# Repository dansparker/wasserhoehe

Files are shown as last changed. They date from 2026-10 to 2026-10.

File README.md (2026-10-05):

# wasserhoehe

Misst die Wasserhöhe in einem ca. 3 m tiefen Brunnenschacht per Ultraschall und schickt den Wert über Zigbee an Home Assistant (Zigbee2MQTT).

```
JSN-SR04T ──► STM32F103 (Bluepill) ──UART──► CC2530 (PTVO-Firmware) ──Zigbee──► Zigbee2MQTT ──► Home Assistant
```

## Hardware

| Teil | Aufgabe |
|---|---|
| JSN-SR04T (wasserdicht) | Abstand Sensor → Wasseroberfläche, 25–450 cm |
| STM32F103C8T6 Bluepill | Messung, Filterung, Sendelogik |
| TENSTAR CC2530 | Zigbee-Router mit [PTVO-Firmware](https://ptvo.info/zigbee-configurable-firmware-features/) (UART → Zigbee) |
| DS18B20 wasserdicht (optional) | Lufttemperatur im Schacht für die Schallgeschwindigkeit |
| 5-V-Netzteil (≥ 1 A) | Versorgung |

### Verdrahtung

| Von | Nach | Hinweis |
|---|---|---|
| Netzteil +5 V | JSN-SR04T **5V**, Bluepill **5V** | |
| Netzteil GND | JSN-SR04T **GND**, Bluepill **GND**, CC2530 **GND** | gemeinsame Masse! |
| Bluepill **3.3** | CC2530 **VCC** | bei CC2530 mit Verstärker (CC2591) besser eigener AMS1117-3.3 |
| Bluepill **PB7** | JSN-SR04T **Trig** | 3,3 V reichen |
| JSN-SR04T **Echo** | Bluepill **PB6** | 5-V-Pegel, PB6 ist 5-V-tolerant |
| Bluepill **PA9** (TX) | CC2530 **P0.2** (RX) | 9600 Baud, 8N1, beide 3,3 V |
| DS18B20 **DQ** (gelb) | Bluepill **PB8** | optional; **4,7 kΩ** von DQ nach 3,3 V |
| DS18B20 **VDD** (rot) / **GND** (schwarz) | Bluepill **3.3** / **GND** | nicht parasitär betreiben |

PC13 (Onboard-LED) leuchtet während einer Messung.

### Montage

- Elektronik in einer Box **oben** am Schachtdeckel, nur der wasserdichte Schallkopf hängt im Schacht (Kabel 2,5 m).
- Schallkopf **senkrecht und mittig** ausrichten, Abstand zu Wänden, Leitern und Rohren: Der Schallkegel ist breit (≈ 45–75°), Wandechos sind der häufigste Messfehler.
- Den DS18B20 neben dem Schallkopf **in der Schachtluft** aufhängen, nicht in der Box und nicht im Wasser.
- `MOUNT_MM` in [main.c](firmware/src/main.c) = Abstand von der Schallkopf-Fläche zum Schachtboden.
- Die Antenne bzw. den CC2530 nicht unter einem Metall- oder Betondeckel einbauen, sonst kommt kaum Funk durch.

## Gehäuse (3D-Druck)

Im Ordner [gehaeuse/](gehaeuse/) liegen die fertigen STL-Dateien und das parametrische Skript [gehaeuse.py](gehaeuse/gehaeuse.py). Neu erzeugen mit `pip install manifold3d numpy`, dann `python gehaeuse.py`.

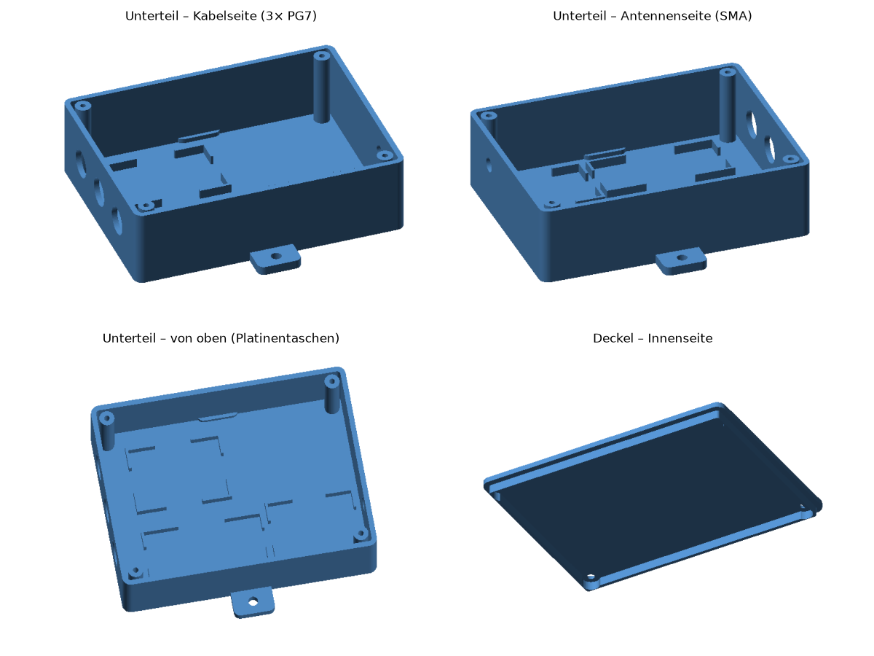
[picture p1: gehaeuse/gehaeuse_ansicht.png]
Gehäuse


| | |
|---|---|
| Außenmaß | 120 × 91 × 34 mm (Unterteil) + 2,4 mm Deckel, Laschen für 4-mm-Schrauben |
| Innen | Taschen für Bluepill, CC2530 und die JSN-Platine (Rippen mit Kabeldurchlässen; Platinen mit Heißkleber oder doppelseitigem Klebeband fixieren) |
| Kabelseite | 3 × Ø 12,5 mm für **PG7-Kabelverschraubungen**: Ultraschallsensor, DS18B20, Netzteil |
| Gegenseite | Ø 6,5 mm für eine **SMA-Antennenbuchse** (`ANT_D = 0` → kein Loch, falls der CC2530 eine PCB-Antenne hat) |
| Deckel | Innenliegender Rand, 4 × M3-Senkkopf, in Dome mit 2,5-mm-Loch (selbstschneidend) |

**Druck:** PETG oder ASA (PLA wird im feuchten Schacht weich und spröde), 0,2-mm-Schichten, 3 Wände, ohne Stützen. Das Unterteil steht aufrecht, der Deckel liegt mit der Außenseite nach unten.

**Einbau:** Die Kabelverschraubungen sollen **nach unten** zeigen, dann läuft Tropfwasser ab. Für Dichtheit eine Silikonraupe oder ein Moosgummiband unter den Deckelrand legen und einen **Silica-Gel-Beutel** ins Gehäuse geben. Wichtig: Die Maße der TENSTAR-Platine vor dem Druck nachmessen und in `BOARDS` eintragen.

## Messverfahren

Messprinzip

Jede Messung besteht aus 9 Pings. Ungültige Werte und Wandechos werden verworfen, der Rest gemittelt:

Filterung

Gesendet wird nur, wenn sich etwas ändert oder das Heartbeat-Intervall abgelaufen ist:

Sendelogik

## Übertragung / Intervall

| Parameter | Wert | Begründung |
|---|---|---|
| Messung | alle **10 s**, je 9 Pings (70 ms Abstand) | Der Pegel ändert sich langsam; mehrere Pings filtern Ausreißer |
| Senden bei Änderung | **≥ 1 cm** | Pumpen oder Nachfüllen sind sofort sichtbar |
| Heartbeat | spätestens alle **5 min** | Home Assistant erkennt, ob das Gerät noch lebt; ein verlorenes Paket wird so wieder ausgeglichen |
| Fehlermeldung | erst nach **3 Fehlmessungen** in Folge | kein Flattern bei einzelnen Störungen |

Das ergibt im Ruhezustand ca. 12 Nachrichten pro Stunde. Weil das Gerät am Netzteil hängt, läuft der CC2530 als **Router** und verstärkt damit auch das Zigbee-Netz.

Telegramm (ASCII): `L=1800;D=1200;S=0;T=9` – Pegel in mm, Distanz in mm, Status (0 = OK, 1 = kein Echo, 2 = instabil), verwendete Temperatur in °C.

**Temperatur:** Ist ein DS18B20 angeschlossen, startet bei jeder Messung eine Wandlung, die parallel zu den Pings läuft. Fehlt der Sensor, rechnet die Firmware mit `TEMP_DEFAULT_C` = 10 °C. Einzelne Lesefehler überbrückt der letzte gültige Wert (bis 1 min). Fehlerhafte Werte werden verworfen: CRC-Fehler, der 85-°C-Einschaltwert und alles außerhalb von −40…60 °C.

## Firmware STM32

PlatformIO (CMSIS, ohne HAL):

```bash
cd firmware
pio run -t upload
```

Zum Flashen braucht man einen ST-Link (SWDIO, SWCLK, GND, 3.3V). Messintervall, Schwellwerte und Temperatur stehen oben in [main.c](firmware/src/main.c).

## Firmware CC2530 (PTVO)

Für eine eigene Z-Stack-Firmware bräuchte man den kostenpflichtigen IAR-8051-Compiler. Deshalb läuft auf dem CC2530 die kostenlose PTVO-Firmware.

1. Den PTVO-Konfigurator von [ptvo.info](https://ptvo.info) laden.
2. Einstellungen: Board **CC2530**, Device type **Router**, Output **UART** mit 9600 Baud. Die Pins (Standard RX = P0.2, TX = P0.3) im Konfigurator kontrollieren.
3. Die Firmware mit einem CC-Debugger (oder einem Arduino oder ESP mit CCLib) flashen.
4. In Zigbee2MQTT „Permit join“ aktivieren und das Gerät in **brunnen** umbenennen. Die per UART empfangenen Zeilen kommen als `action` an.
5. Den Inhalt von [homeassistant/brunnen.yaml](homeassistant/brunnen.yaml) in die Home-Assistant-Konfiguration übernehmen.

## Tests

Die Messlogik ([level.c](firmware/src/level.c)) hängt nicht von der Hardware ab und wird am PC getestet:

```bash
cd test
python -m ziglang cc -I../firmware/src test_level.c ../firmware/src/level.c -o t.exe && ./t.exe
```

Getestet werden Umrechnung, DS18B20-Dekodierung (CRC, negative Werte, 85-°C-Einschaltwert, offener oder kurzgeschlossener Bus), Temperatureinfluss, Ausreißer (Wandecho, Timeout, Blindzone), kein Echo, starke Streuung, leerer Schacht, Array-Überlauf, Sendelogik (Delta, Heartbeat, Fehlerentprellung), Zähler-Überlauf nach 49 Tagen und das Telegramm-Format.

## Bekannte Schwachstellen und Gegenmaßnahmen

| Schwachstelle | Gegenmaßnahme |
|---|---|
| Wandechos oder Leiter im Schacht | Median + Mittelung nur im ±3-cm-Fenster, mindestens 5 von 9 Echos nötig, sonst Status „instabil“ |
| Wasser < 25 cm unter Sensor (Blindzone) | wird als Fehler gemeldet; Sensor ≥ 30 cm über max. Wasserstand montieren |
| Schallgeschwindigkeit hängt von der Temperatur ab (≈ 5 mm pro °C bei 3 m) | DS18B20 im Schacht (optional), sonst fest 10 °C. Der interne STM32-Sensor ist ungeeignet (misst den Chip, ab Werk ±20 °C) |
| Kondenswasser am Schallkopf | Schallkopf leicht schräg bzw. mit Abtropfkante montieren; zeigt sich als „kein Echo“ |
| Bluepill-Clone ohne funktionierenden Quarz | Automatischer Rückfall auf den internen 8-MHz-Takt |
| Hänger (EMV, Echo-Leitung klemmt) | Hardware-Watchdog (~26 s), Timeouts bei allen Warteschleifen |
| Kabelbruch Echo-Leitung | Pull-down an PB6 → Status „kein Echo“ |
| Funkverlust | Heartbeat alle 5 min; CC2530 als Router meldet sich automatisch wieder an |
| CC2530 noch nicht im Netz beim Start | 3 s Startverzögerung, erste verlorene Meldung wird durch Heartbeat ersetzt |

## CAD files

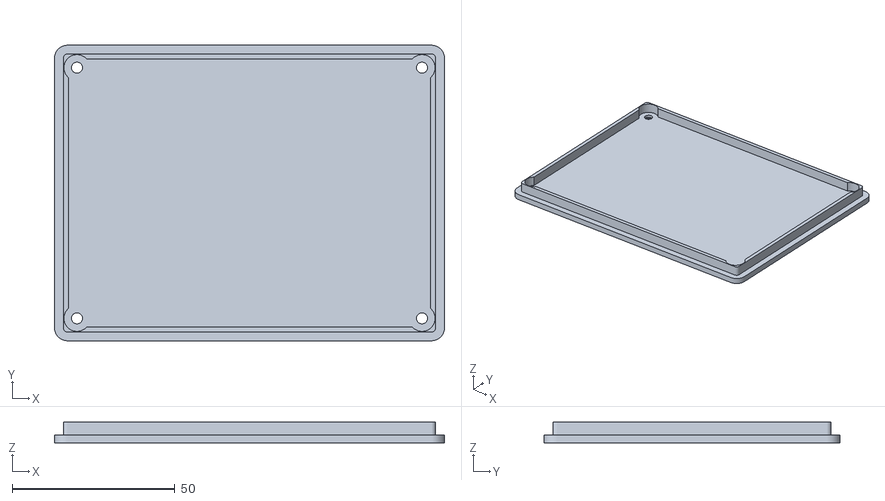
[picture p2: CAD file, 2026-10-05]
gehaeuse/gehaeuse_deckel.stl
119.8 x 90.8 x 6.40

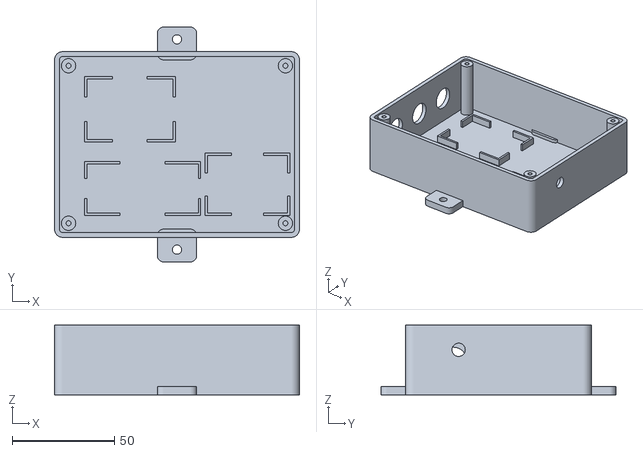
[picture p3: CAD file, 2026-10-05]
gehaeuse/gehaeuse_unterteil.stl
119.8 x 114.8 x 34.0

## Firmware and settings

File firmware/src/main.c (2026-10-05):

/*
 * Wasserhoehe im Brunnenschacht - STM32F103C8T6 (Bluepill)
 *
 *  JSN-SR04T  TRIG -> PB7        ECHO (5 V) -> PB6 (5V-tolerant)
 *  CC2530     RX (P0.2) <- PA9 (USART1 TX, 9600 8N1)
 *  DS18B20    DQ -> PB8 (optional, 4,7 kOhm Pull-up nach 3,3 V)
 *  LED        PC13 (aktiv low), blinkt bei jeder Messung
 */
#include "stm32f1xx.h"
#include "level.h"

/* ---------- Konfiguration ------------------------------------------ */
#define MOUNT_MM        3000u    /* Sensorflaeche ueber Schachtboden  */
#define TEMP_DEFAULT_C  10       /* ohne DS18B20 / bei Lesefehler     */
#define TEMP_KEEP       6        /* letzten DS18B20-Wert so oft halten */
#define SAMPLES         9        /* Pings pro Messung                 */
#define PING_GAP_MS     70       /* Nachhall abklingen lassen         */
#define MEAS_PERIOD_MS  10000u   /* alle 10 s messen                  */
#define DELTA_MM        10u      /* senden bei >= 1 cm Aenderung      */
#define HEARTBEAT_MS    300000u  /* spaetestens alle 5 min senden     */
#define FAIL_LIMIT      3        /* Fehler erst nach 3 Fehlmessungen  */
#define UART_BAUD       9600u
#define ECHO_TIMEOUT_US 30000u   /* ~5 m                              */

#define TRIG_PIN  (1u << 7)
#define ECHO_PIN  (1u << 6)
#define LED_PIN   (1u << 13)
#define OW_PIN    (1u << 8)
#define ECHO_HIGH (GPIOB->IDR & ECHO_PIN)

static volatile uint32_t ms_ticks;
static uint32_t sysclk_hz, pclk1_tim_hz, pclk2_hz;

void SysTick_Handler(void) { ms_ticks++; }

static void clock_init(void)
{
    /* HSE 8 MHz -> PLL x9 = 72 MHz; Fallback HSI 8 MHz (Clone ohne Quarz) */
    RCC->CR |= RCC_CR_HSEON;
    for (uint32_t t = 0; t < 200000u && !(RCC->CR & RCC_CR_HSERDY); t++) { }

    if (RCC->CR & RCC_CR_HSERDY) {
        FLASH->ACR = FLASH_ACR_PRFTBE | FLASH_ACR_LATENCY_2;
        RCC->CFGR  = RCC_CFGR_PLLSRC | RCC_CFGR_PLLMULL9 | RCC_CFGR_PPRE1_DIV2;
        RCC->CR   |= RCC_CR_PLLON;
        while (!(RCC->CR & RCC_CR_PLLRDY)) { }
        RCC->CFGR |= RCC_CFGR_SW_PLL;
        while ((RCC->CFGR & RCC_CFGR_SWS) != RCC_CFGR_SWS_PLL) { }
        sysclk_hz = 72000000u; pclk1_tim_hz = 72000000u; pclk2_hz = 72000000u;
    } else {
        RCC->CR &= ~RCC_CR_HSEON;
        sysclk_hz = pclk1_tim_hz = pclk2_hz = 8000000u;
    }
}

static void periph_init(void)
{
    RCC->APB2ENR |= RCC_APB2ENR_IOPAEN | RCC_APB2ENR_IOPBEN | RCC_APB2ENR_IOPCEN
                  | RCC_APB2ENR_USART1EN;
    RCC->APB1ENR |= RCC_APB1ENR_TIM2EN;

    /* PB7 Push-Pull 2 MHz, PB6 Eingang mit Pull-down (offenes Kabel = low) */
    GPIOB->CRL = (GPIOB->CRL & ~(0xFFu << 24)) | (0x2u << 28) | (0x8u << 24);
    GPIOB->BRR = TRIG_PIN | ECHO_PIN;
    /* PB8 Open-Drain 2 MHz, losgelassen (1-Wire) */
    GPIOB->CRH = (GPIOB->CRH & ~0xFu) | 0x6u;
    GPIOB->BSRR = OW_PIN;
    /* PA9 AF Push-Pull 2 MHz */
    GPIOA->CRH = (GPIOA->CRH & ~(0xFu << 4)) | (0xAu << 4);
    /* PC13 Push-Pull 2 MHz, LED aus */
    GPIOC->CRH = (GPIOC->CRH & ~(0xFu << 20)) | (0x2u << 20);
    GPIOC->BSRR = LED_PIN;

    /* TIM2: freilaufend, 1 MHz */
    TIM2->PSC = (uint16_t)(pclk1_tim_hz / 1000000u - 1u);
    TIM2->ARR = 0xFFFF;
    TIM2->EGR = TIM_EGR_UG;
    TIM2->CR1 = TIM_CR1_CEN;

    USART1->BRR = (uint16_t)((pclk2_hz + UART_BAUD / 2u) / UART_BAUD);
    USART1->CR1 = USART_CR1_UE | USART_CR1_TE;

    SysTick_Config(sysclk_hz / 1000u);

    /* Watchdog: LSI 40 kHz / 256 * 4095 ~ 26 s */
    IWDG->KR  = 0x5555;
    IWDG->PR  = 6;
    IWDG->RLR = 0xFFF;
    IWDG->KR  = 0xCCCC;
}

static inline void wdg_feed(void) { IWDG->KR = 0xAAAA; }

static void delay_us(uint16_t us)
{
    uint16_t t0 = (uint16_t)TIM2->CNT;
    while ((uint16_t)(TIM2->CNT - t0) < us) { }
}

static void delay_ms(uint32_t ms)
{
    uint32_t t0 = ms_ticks;
    while (ms_ticks - t0 < ms) __WFI();
}

/* Liefert Echo-Laufzeit in us, 0 bei Fehler/Timeout. */
static uint16_t ping_us(void)
{
    uint16_t t0 = (uint16_t)TIM2->CNT;
    while (ECHO_HIGH)                                  /* altes Echo noch aktiv */
        if ((uint16_t)(TIM2->CNT - t0) > ECHO_TIMEOUT_US) return 0;

    GPIOB->BSRR = TRIG_PIN;
    delay_us(20);                                      /* >= 10 us, v3 mag 20 */
    GPIOB->BRR = TRIG_PIN;

    t0 = (uint16_t)TIM2->CNT;
    while (!ECHO_HIGH)
        if ((uint16_t)(TIM2->CNT - t0) > 10000u) return 0;

    __disable_irq();                                   /* SysTick-Jitter vermeiden */
    uint16_t ts = (uint16_t)TIM2->CNT, dt;
    while (ECHO_HIGH) {
        dt = (uint16_t)(TIM2->CNT - ts);
        if (dt > ECHO_TIMEOUT_US) { __enable_irq(); return 0; }
    }
    dt = (uint16_t)(TIM2->CNT - ts);
    __enable_irq();
    return dt;
}

/* ---------- 1-Wire / DS18B20 ------------------------------------------ */
#define OW_LOW()   (GPIOB->BRR  = OW_PIN)
#define OW_REL()   (GPIOB->BSRR = OW_PIN)
#define OW_READ()  ((GPIOB->IDR & OW_PIN) != 0)

static int ow_reset(void)
{
    if (!OW_READ()) return 0;                          /* Bus kurz / kein Pull-up */
    OW_LOW();  delay_us(480);
    __disable_irq();
    OW_REL();  delay_us(70);
    int present = !OW_READ();
    __enable_irq();
    delay_us(410);
    return present;
}

static int ow_bit(int b)
{
    __disable_irq();
    OW_LOW();  delay_us(b ? 3 : 60);
    OW_REL();
    if (b) delay_us(9);
    int r = OW_READ();
    __enable_irq();
    delay_us(b ? 55 : 10);
    return r;
}

static void ow_write(uint8_t v)
{
    for (int i = 0; i < 8; i++, v >>= 1) ow_bit(v & 1u);
}

static uint8_t ow_read(void)
{
    uint8_t v = 0;
    for (int i = 0; i < 8; i++) v |= (uint8_t)(ow_bit(1) << i);
    return v;
}

/* Startet Wandlung (750 ms, laeuft parallel zu den Pings). */
static int ds_start(void)
{
    if (!ow_reset()) return 0;
    ow_write(0xCC);                                    /* Skip ROM: nur ein Sensor */
    ow_write(0x44);                                    /* Convert T */
    return 1;
}

static int ds_read(int8_t *t)
{
    uint8_t sp[9];
    uint32_t t0 = ms_ticks;
    while (!ow_bit(1))                                 /* 1 = Wandlung fertig */
        if (ms_ticks - t0 > 800u) return 0;
    if (!ow_reset()) return 0;
    ow_write(0xCC);
    ow_write(0xBE);                                    /* Read Scratchpad */
    for (int i = 0; i < 9; i++) sp[i] = ow_read();
    return ds18b20_decode(sp, t);
}

static void uart_puts(const char *s)
{
    while (*s) {
        while (!(USART1->SR & USART_SR_TXE)) { }
        USART1->DR = (uint8_t)*s++;
    }
    while (!(USART1->SR & USART_SR_TC)) { }
}

int main(void)
{
    static level_cfg_t cfg = {
        .mount_mm  = MOUNT_MM,
        .min_mm    = 250,
        .max_mm    = MOUNT_MM + 200,   /* Toleranz fuer Temperaturfehler */
        .window_mm = 30,
        .min_valid = SAMPLES / 2 + 1,
        .temp_c    = TEMP_DEFAULT_C,
    };
    report_state_t rs = { 0 };
    uint16_t echo[SAMPLES];
    char msg[32];
    uint8_t temp_fail = TEMP_KEEP;

    clock_init();
    periph_init();
    delay_ms(3000);                    /* CC2530 booten / Netz beitreten lassen */

    uint32_t last = ms_ticks - MEAS_PERIOD_MS;
    for (;;) {
        wdg_feed();
        if (ms_ticks - last >= MEAS_PERIOD_MS) {
            last = ms_ticks;
            GPIOC->BRR = LED_PIN;
            int ds = ds_start();
            for (int i = 0; i < SAMPLES; i++) {
                echo[i] = ping_us();
                delay_ms(PING_GAP_MS);
            }
            GPIOC->BSRR = LED_PIN;

            int8_t t;
            if (ds && ds_read(&t)) {
                cfg.temp_c = t;
                temp_fail = 0;
            } else if (temp_fail < TEMP_KEEP) {
                temp_fail++;                           /* Einzelfehler: alten Wert halten */
            } else {
                cfg.temp_c = TEMP_DEFAULT_C;           /* kein Sensor angeschlossen */
            }

            level_meas_t m = level_evaluate(&cfg, echo, SAMPLES);
            if (report_should_send(&rs, &m, ms_ticks, DELTA_MM, HEARTBEAT_MS, FAIL_LIMIT)) {
                level_format(msg, &m, cfg.temp_c);
                uart_puts(msg);
            }
        }
        __WFI();
    }
}

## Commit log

2026-10-05 Wasserhoehe: STM32-Firmware, Tests, PTVO/Home-Assistant-Anleitung
2026-10-05 Optionaler DS18B20 fuer Temperaturkompensation (Fallback 10 C)
2026-10-05 3D-druckbares Gehaeuse (parametrisch, STL)
    [gehaeuse_deckel.stl, gehaeuse_unterteil.stl]
